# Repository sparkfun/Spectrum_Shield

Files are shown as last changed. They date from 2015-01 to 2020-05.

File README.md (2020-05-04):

SparkFun Spectrum Shield
========================

SparkFun Spectrum Shield (https://www.sparkfun.com/products/13116)

[*SparkFun Spectrum Shield (DEV-13116)*](https://www.sparkfun.com/products/13116)

 This shield can be used to create sound visualizers, detect patterns in music or add sound activation to your microcontroller projects.

Repository Contents
-------------------
* **/Firmware** - Example Arduino Sketch
* **/Hardware** - All Eagle design files (.brd, .sch)
* **/Production** - Test bed files and production panel files

Documentation
--------------
* **[Hookup Guide](https://learn.sparkfun.com/tutorials/spectrum-shield-hookup-guide-v2)** - Basic hookup guide for the Spectrum Shield.
* **[SparkFun Fritzing repo](https://github.com/sparkfun/Fritzing_Parts)** - Fritzing diagrams for SparkFun products.
* **[SparkFun 3D Model repo](https://github.com/sparkfun/3D_Models)** - 3D models of SparkFun products. 

Product Versions
----------------
* [DEV-13116](https://www.sparkfun.com/products/13116) - Version 1.6
* [DEV-10306](https://www.sparkfun.com/products/10306) - Version 1.4. Retired. 

License Information
-------------------

This product is _**open source**_! 

Please review the LICENSE.md file for license information. 

If you have any questions or concerns on licensing, please contact technical support on our [SparkFun forums](https://forum.sparkfun.com/viewforum.php?f=152).

Distributed as-is; no warranty is given.

- Your friends at SparkFun.

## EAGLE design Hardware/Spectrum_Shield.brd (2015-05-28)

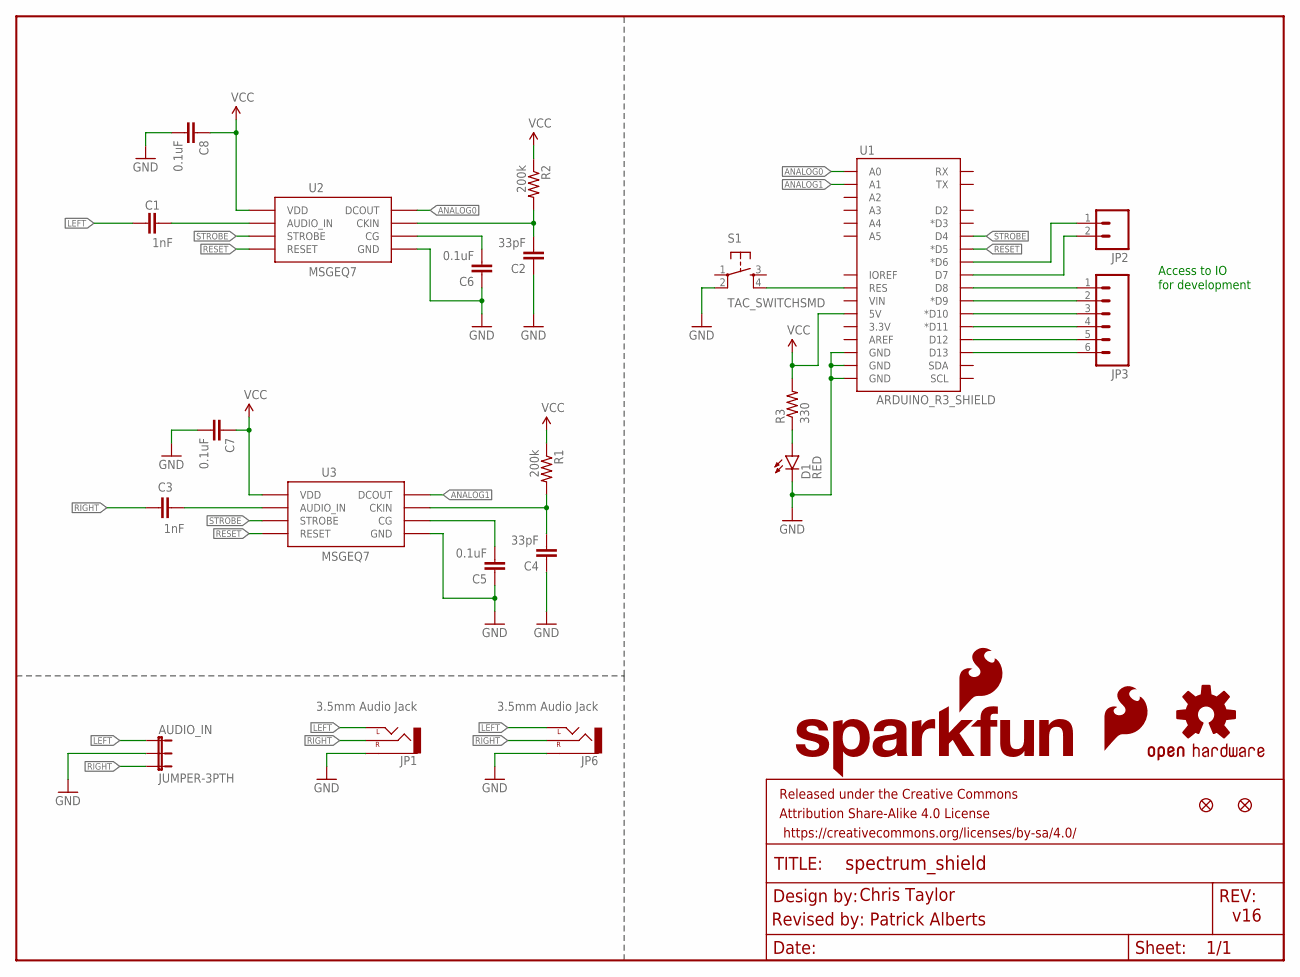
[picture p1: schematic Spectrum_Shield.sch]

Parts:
AUDIO_IN: JUMPER-3PTH; 1X03
C1, C3: 1nF; 0603-CAP
C2, C4: 33pF; 0603-CAP
C5, C6, C7, C8: 0.1uF; 0603-CAP
D1: RED; LED-0603
FRAME1: FRAME-LETTER; CREATIVE_COMMONS
JP1, JP6: 3.5mm Audio Jack; AUDIO-JACK-3.5MM-SMD
JP2: M02PTH; 1X02
JP3: M06SIP; 1X06
JP4, JP5: FIDUCIAL1X2; FIDUCIAL-1X2
LOGO1: OSHW-LOGOM; OSHW-LOGO-M
LOGO2: SFE_LOGO_FLAME.2_INCH; SFE_LOGO_FLAME_.2
LOGO3: SFE_LOGO_NAME_FLAME.1_INCH; SFE_LOGO_NAME_FLAME_.1
R1, R2: 200k; 0603-RES
R3: 330; 0603-RES
S1: TAC_SWITCHSMD; TACTILE-SWITCH-SMD
U1: ARDUINO_R3_SHIELD; UNO_R3_SHIELD
U2, U3: MSGEQ7SOIC; SOIC8

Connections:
ANALOG0: U1.A0, U2.3 (DCOUT)
ANALOG1: U1.A1, U3.3 (DCOUT)
GND: AUDIO_IN.2, C2.1, C4.1, C5.1, C6.1, C7.2, C8.2, D1.C, JP1.SLEEVE, JP6.SLEEVE, S1.2, U1.GND@0 (GND), U1.GND@1 (GND), U1.GND@2 (GND), U2.2 (GND), U3.2 (GND)
LEFT: AUDIO_IN.1, C1.1, JP1.TIP (LEFT), JP6.TIP (LEFT)
unnamed: C1.2, U2.5 (AUDIO_IN)
unnamed: C3.2, U3.5 (AUDIO_IN)
unnamed: C4.2, R1.2, U3.8 (CKIN)
unnamed: C2.2, R2.2, U2.8 (CKIN)
unnamed: C5.2, U3.6 (CG)
unnamed: C6.2, U2.6 (CG)
unnamed: D1.A, R3.1
unnamed: JP2.1, U1.D6 (*D6)
unnamed: JP2.2, U1.D7
unnamed: JP3.1, U1.D8
unnamed: JP3.2, U1.D9 (*D9)
unnamed: JP3.3, U1.D10 (*D10)
unnamed: JP3.4, U1.D11 (*D11)
unnamed: JP3.5, U1.D12
unnamed: JP3.6, U1.D13
unnamed: S1.4, U1.RES
RESET: U1.D5 (*D5), U2.7 (RESET), U3.7 (RESET)
RIGHT: AUDIO_IN.3, C3.1, JP1.RING (RIGHT), JP6.RING (RIGHT)
STROBE: U1.D4, U2.4 (STROBE), U3.4 (STROBE)
VCC: C7.1, C8.1, R1.1, R2.1, R3.2, U1.5V, U2.1 (VDD), U3.1 (VDD)

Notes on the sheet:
Access to IO
for development
v16
Chris Taylor
Revised by: Patrick Alberts

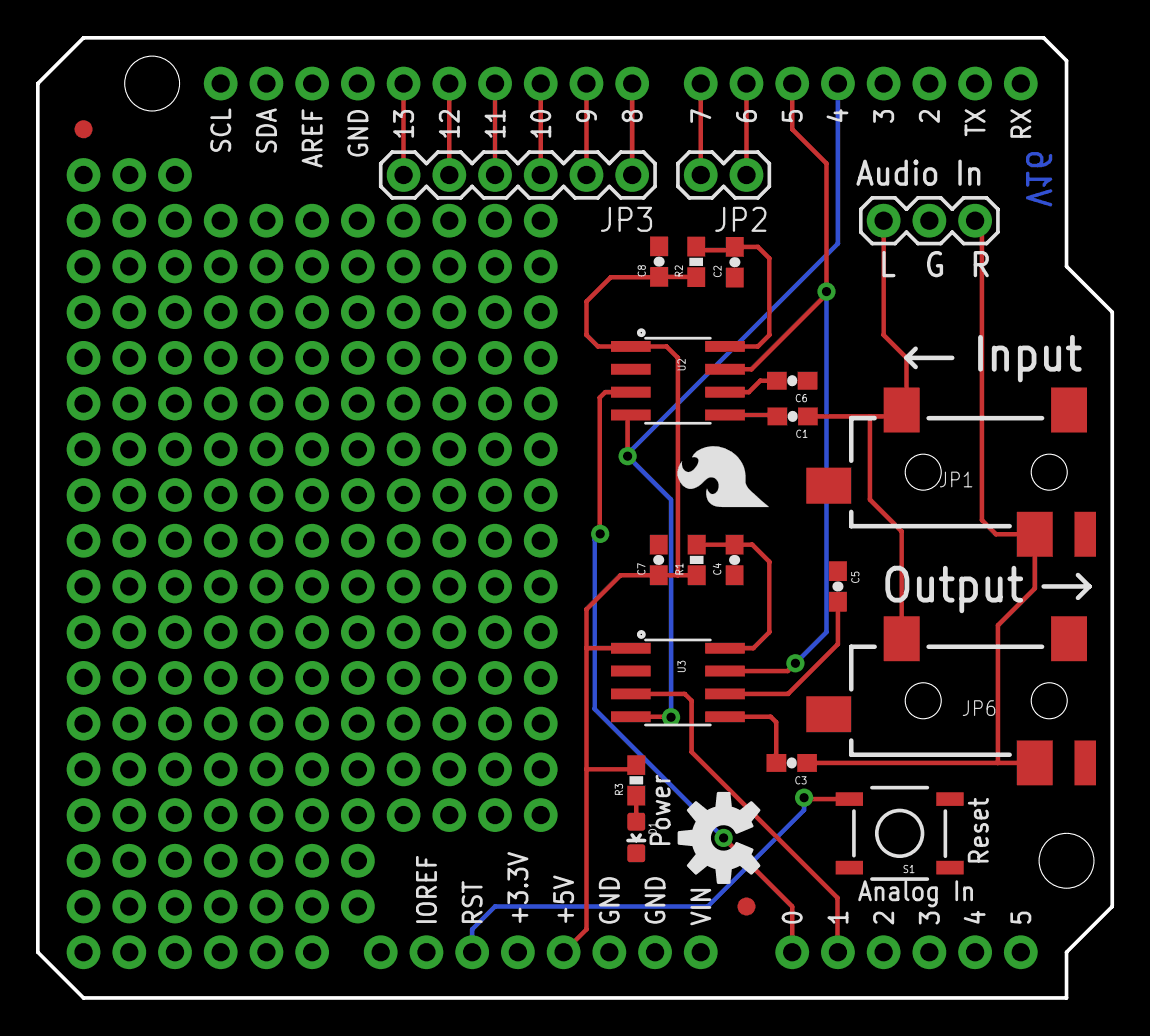
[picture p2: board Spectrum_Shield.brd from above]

Board: 2 copper layers, 59.7 x 53.3 mm, 29 parts (1 on the bottom side), 24 nets.

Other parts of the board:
U$1, U$3: STAND-OFF-TIGHT

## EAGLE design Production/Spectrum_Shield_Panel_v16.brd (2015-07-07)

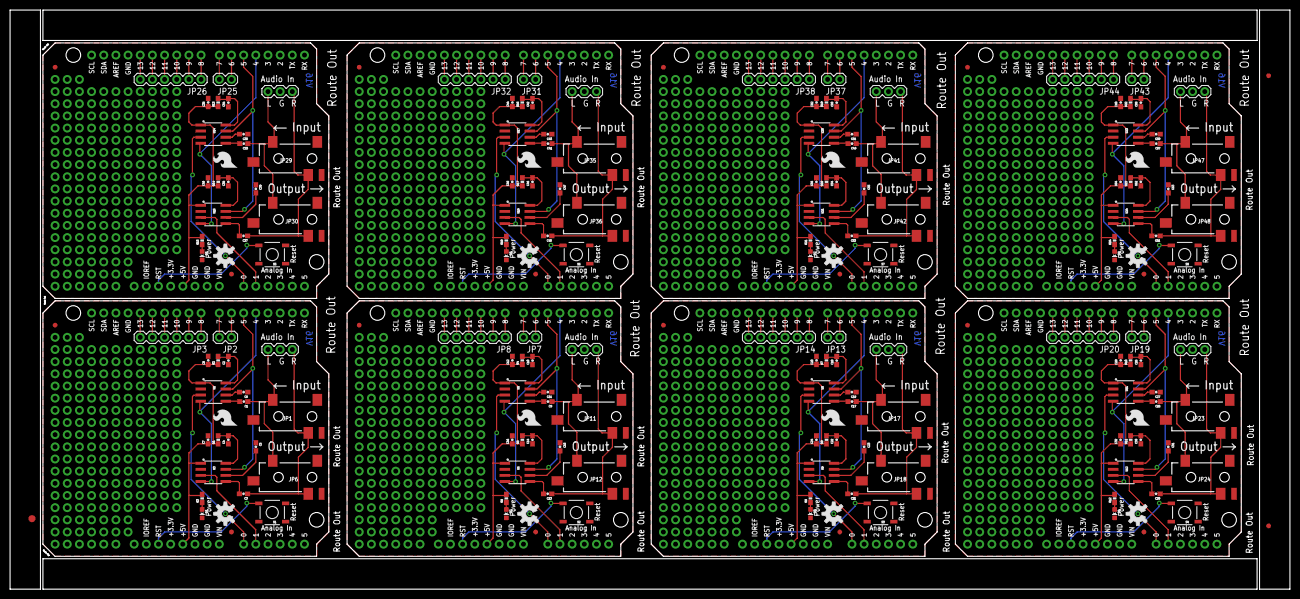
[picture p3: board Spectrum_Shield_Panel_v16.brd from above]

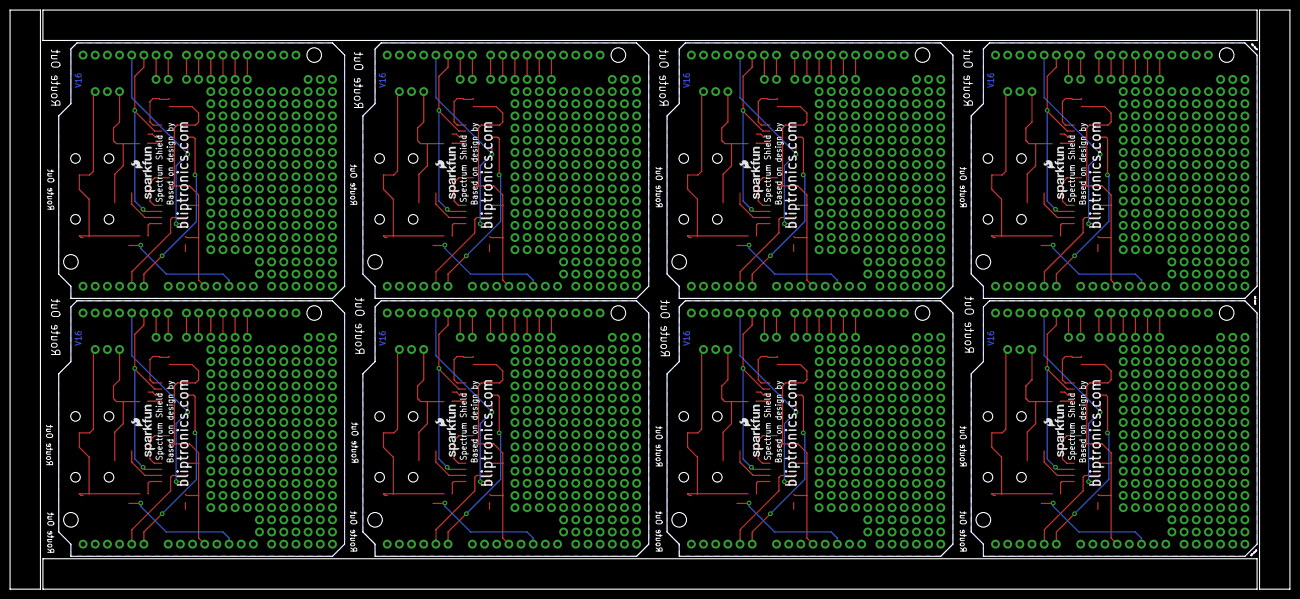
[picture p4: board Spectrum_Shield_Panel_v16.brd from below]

Board: 2 copper layers, 267.2 x 120.9 mm, 227 parts (8 on the bottom side), 192 nets.

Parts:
AUDIO_IN, AUDIO_IN1, AUDIO_IN2, AUDIO_IN3, AUDIO_IN4, AUDIO_IN5, AUDIO_IN6, AUDIO_IN7: JUMPER-3PTH; 1X03
C1, C3, C9, C13, C17, C21, C25, C29, C33, C37, C41, C45, C49, C53, C57, C61: 1nF; 0603-CAP
C2, C4, C10, C14, C18, C22, C26, C30, C34, C38, C42, C46, C50, C54, C58, C62: 33pF; 0603-CAP
C5, C6, C7, C8, C11, C12, C15, C16, C19, C20, C23, C24, C27, C28, C31, C32, C35, C36, C39, C40, C43, C44, C47, C48, C51, C52, C55, C56, C59, C60, C63, C64: 0.1uF; 0603-CAP
D1, D2, D3, D4, D5, D6, D7, D8: RED; LED-0603
E$1, E$2: FIDUCIAL-1X2
E$3: FIDUCIAL-1.5X3
JP1, JP6, JP11, JP12, JP17, JP18, JP23, JP24, JP29, JP30, JP35, JP36, JP41, JP42, JP47, JP48: 3.5mm Audio Jack; AUDIO-JACK-3.5MM-SMD
JP2, JP7, JP13, JP19, JP25, JP31, JP37, JP43: 1X02
JP3, JP8, JP14, JP20, JP26, JP32, JP38, JP44: 1X06
JP4, JP5, JP9, JP10, JP15, JP16, JP21, JP22, JP27, JP28, JP33, JP34, JP39, JP40, JP45, JP46: FIDUCIAL1X2; FIDUCIAL-1X2
LOGO1, LOGO4, LOGO7, LOGO10, LOGO13, LOGO16, LOGO19, LOGO22: OSHW-LOGOM; OSHW-LOGO-M
LOGO2, LOGO6, LOGO9, LOGO12, LOGO15, LOGO18, LOGO21, LOGO24: SFE_LOGO_FLAME.2_INCH; SFE_LOGO_FLAME_.2
LOGO3, LOGO5, LOGO8, LOGO11, LOGO14, LOGO17, LOGO20, LOGO23: SFE_LOGO_NAME_FLAME.1_INCH; SFE_LOGO_NAME_FLAME_.1
R1, R2, R4, R5, R7, R8, R10, R11, R13, R14, R16, R17, R19, R20, R22, R23: 200k; 0603-RES
R3, R6, R9, R12, R15, R18, R21, R24: 330; 0603-RES
S1, S2, S3, S4, S5, S6, S7, S8: TAC_SWITCHSMD; TACTILE-SWITCH-SMD
U1, U4, U7, U10, U13, U16, U19, U22: ARDUINO_R3_SHIELD; UNO_R3_SHIELD
U2, U3, U5, U6, U8, U9, U11, U12, U14, U15, U17, U18, U20, U21, U23, U24: MSGEQ7SOIC; SOIC8
U$1, U$2, U$3, U$4, U$5, U$6, U$7, U$8, U$9, U$10, U$11, U$12, U$13, U$14, U$15, U$16: STAND-OFF-TIGHT

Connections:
ANALOG0: U1.A0, U2.3
ANALOG1: U1.A1, U3.3
ANALOG2: U4.A0, U5.3
ANALOG3: U4.A1, U6.3
ANALOG4: U7.A0, U8.3
ANALOG5: U7.A1, U9.3
ANALOG6: U10.A0, U11.3
ANALOG7: U10.A1, U12.3
ANALOG8: U13.A0, U14.3
ANALOG9: U13.A1, U15.3
ANALOG10: U16.A0, U17.3
ANALOG11: U16.A1, U18.3
ANALOG12: U19.A0, U20.3
ANALOG13: U19.A1, U21.3
ANALOG14: U22.A0, U23.3
ANALOG15: U22.A1, U24.3
GND: AUDIO_IN.2, C2.1, C4.1, C5.1, C6.1, C7.2, C8.2, D1.C, JP1.SLEEVE, JP6.SLEEVE, S1.2, U1.GND@0, U1.GND@1, U1.GND@2, U2.2, U3.2
GND1: AUDIO_IN1.2, C10.1, C11.1, C12.2, C14.1, C15.1, C16.2, D2.C, JP11.SLEEVE, JP12.SLEEVE, S2.2, U4.GND@0, U4.GND@1, U4.GND@2, U5.2, U6.2
GND2: AUDIO_IN2.2, C18.1, C19.1, C20.2, C22.1, C23.1, C24.2, D3.C, JP17.SLEEVE, JP18.SLEEVE, S3.2, U7.GND@0, U7.GND@1, U7.GND@2, U8.2, U9.2
GND3: AUDIO_IN3.2, C26.1, C27.1, C28.2, C30.1, C31.1, C32.2, D4.C, JP23.SLEEVE, JP24.SLEEVE, S4.2, U10.GND@0, U10.GND@1, U10.GND@2, U11.2, U12.2
GND4: AUDIO_IN4.2, C34.1, C35.1, C36.2, C38.1, C39.1, C40.2, D5.C, JP29.SLEEVE, JP30.SLEEVE, S5.2, U13.GND@0, U13.GND@1, U13.GND@2, U14.2, U15.2
GND5: AUDIO_IN5.2, C42.1, C43.1, C44.2, C46.1, C47.1, C48.2, D6.C, JP35.SLEEVE, JP36.SLEEVE, S6.2, U16.GND@0, U16.GND@1, U16.GND@2, U17.2, U18.2
GND6: AUDIO_IN6.2, C50.1, C51.1, C52.2, C54.1, C55.1, C56.2, D7.C, JP41.SLEEVE, JP42.SLEEVE, S7.2, U19.GND@0, U19.GND@1, U19.GND@2, U20.2, U21.2
GND7: AUDIO_IN7.2, C58.1, C59.1, C60.2, C62.1, C63.1, C64.2, D8.C, JP47.SLEEVE, JP48.SLEEVE, S8.2, U22.GND@0, U22.GND@1, U22.GND@2, U23.2, U24.2
LEFT: AUDIO_IN.1, C1.1, JP1.TIP, JP6.TIP
LEFT1: AUDIO_IN1.1, C9.1, JP11.TIP, JP12.TIP
LEFT2: AUDIO_IN2.1, C17.1, JP17.TIP, JP18.TIP
LEFT3: AUDIO_IN3.1, C25.1, JP23.TIP, JP24.TIP
LEFT4: AUDIO_IN4.1, C33.1, JP29.TIP, JP30.TIP
LEFT5: AUDIO_IN5.1, C41.1, JP35.TIP, JP36.TIP
LEFT6: AUDIO_IN6.1, C49.1, JP41.TIP, JP42.TIP
LEFT7: AUDIO_IN7.1, C57.1, JP47.TIP, JP48.TIP
unnamed: C1.2, U2.5
unnamed: C3.2, U3.5
unnamed: C4.2, R1.2, U3.8
unnamed: C2.2, R2.2, U2.8
unnamed: C5.2, U3.6
unnamed: C6.2, U2.6
unnamed: D1.A, R3.1
unnamed: JP2.1, U1.D6
unnamed: JP2.2, U1.D7
unnamed: JP3.1, U1.D8
unnamed: JP3.2, U1.D9
unnamed: JP3.3, U1.D10
unnamed: JP3.4, U1.D11
unnamed: JP3.5, U1.D12
unnamed: JP3.6, U1.D13
unnamed: C9.2, U5.5
unnamed: C10.2, R4.2, U5.8
unnamed: C11.2, U5.6
unnamed: C13.2, U6.5
unnamed: C14.2, R5.2, U6.8
unnamed: C15.2, U6.6
unnamed: D2.A, R6.1
unnamed: JP7.2, U4.D7
unnamed: JP8.1, U4.D8
unnamed: JP8.2, U4.D9
unnamed: JP8.3, U4.D10
unnamed: JP8.4, U4.D11
unnamed: JP8.5, U4.D12
unnamed: JP8.6, U4.D13
unnamed: S1.4, U1.RES
unnamed: S2.4, U4.RES
unnamed: JP7.1, U4.D6
unnamed: C17.2, U8.5
unnamed: C18.2, R7.2, U8.8
unnamed: C19.2, U8.6
unnamed: C21.2, U9.5
unnamed: C22.2, R8.2, U9.8
unnamed: C23.2, U9.6
unnamed: D3.A, R9.1
unnamed: JP13.2, U7.D7
unnamed: JP14.1, U7.D8
unnamed: JP14.2, U7.D9
unnamed: JP14.3, U7.D10
unnamed: JP14.4, U7.D11
unnamed: JP14.5, U7.D12
unnamed: JP14.6, U7.D13
unnamed: S3.4, U7.RES
unnamed: JP13.1, U7.D6
unnamed: C25.2, U11.5
unnamed: C26.2, R10.2, U11.8
unnamed: C27.2, U11.6
unnamed: C29.2, U12.5
unnamed: C30.2, R11.2, U12.8
unnamed: C31.2, U12.6
unnamed: D4.A, R12.1
unnamed: JP19.2, U10.D7
unnamed: JP20.1, U10.D8
unnamed: JP20.2, U10.D9
unnamed: JP20.3, U10.D10
unnamed: JP20.4, U10.D11
unnamed: JP20.5, U10.D12
unnamed: JP20.6, U10.D13
unnamed: S4.4, U10.RES
unnamed: JP19.1, U10.D6
unnamed: C33.2, U14.5
unnamed: C34.2, R13.2, U14.8
unnamed: C35.2, U14.6
unnamed: C37.2, U15.5
unnamed: C38.2, R14.2, U15.8
unnamed: C39.2, U15.6
unnamed: D5.A, R15.1
unnamed: JP25.2, U13.D7
unnamed: JP26.1, U13.D8
unnamed: JP26.2, U13.D9
unnamed: JP26.3, U13.D10
unnamed: JP26.4, U13.D11
unnamed: JP26.5, U13.D12
unnamed: JP26.6, U13.D13
unnamed: S5.4, U13.RES
unnamed: JP25.1, U13.D6
unnamed: C41.2, U17.5
unnamed: C42.2, R16.2, U17.8
unnamed: C43.2, U17.6
unnamed: C45.2, U18.5
unnamed: C46.2, R17.2, U18.8
unnamed: C47.2, U18.6
unnamed: D6.A, R18.1
unnamed: JP31.2, U16.D7
unnamed: JP32.1, U16.D8
unnamed: JP32.2, U16.D9
unnamed: JP32.3, U16.D10
unnamed: JP32.4, U16.D11
unnamed: JP32.5, U16.D12
unnamed: JP32.6, U16.D13
unnamed: S6.4, U16.RES
unnamed: JP31.1, U16.D6
unnamed: C49.2, U20.5
unnamed: C50.2, R19.2, U20.8
unnamed: C51.2, U20.6
unnamed: C53.2, U21.5
unnamed: C54.2, R20.2, U21.8
unnamed: C55.2, U21.6
unnamed: D7.A, R21.1
unnamed: JP37.2, U19.D7
unnamed: JP38.1, U19.D8
unnamed: JP38.2, U19.D9
unnamed: JP38.3, U19.D10
unnamed: JP38.4, U19.D11
unnamed: JP38.5, U19.D12
unnamed: JP38.6, U19.D13
unnamed: S7.4, U19.RES
unnamed: JP37.1, U19.D6
unnamed: C57.2, U23.5
unnamed: C58.2, R22.2, U23.8
unnamed: C59.2, U23.6
unnamed: C61.2, U24.5
unnamed: C62.2, R23.2, U24.8
unnamed: C63.2, U24.6
unnamed: D8.A, R24.1
unnamed: JP43.2, U22.D7
unnamed: JP44.1, U22.D8
unnamed: JP44.2, U22.D9
unnamed: JP44.3, U22.D10
unnamed: JP44.4, U22.D11
unnamed: JP44.5, U22.D12
unnamed: JP44.6, U22.D13
unnamed: S8.4, U22.RES
unnamed: JP43.1, U22.D6
RESET: U1.D5, U2.7, U3.7
RESET1: U4.D5, U5.7, U6.7
RESET2: U7.D5, U8.7, U9.7
RESET3: U10.D5, U11.7, U12.7
RESET4: U13.D5, U14.7, U15.7
RESET5: U16.D5, U17.7, U18.7
RESET6: U19.D5, U20.7, U21.7
RESET7: U22.D5, U23.7, U24.7
RIGHT: AUDIO_IN.3, C3.1, JP1.RING, JP6.RING
RIGHT1: AUDIO_IN1.3, C13.1, JP11.RING, JP12.RING
RIGHT2: AUDIO_IN2.3, C21.1, JP17.RING, JP18.RING
RIGHT3: AUDIO_IN3.3, C29.1, JP23.RING, JP24.RING
RIGHT4: AUDIO_IN4.3, C37.1, JP29.RING, JP30.RING
RIGHT5: AUDIO_IN5.3, C45.1, JP35.RING, JP36.RING
RIGHT6: AUDIO_IN6.3, C53.1, JP41.RING, JP42.RING
RIGHT7: AUDIO_IN7.3, C61.1, JP47.RING, JP48.RING
STROBE: U1.D4, U2.4, U3.4
STROBE1: U4.D4, U5.4, U6.4
STROBE2: U7.D4, U8.4, U9.4
STROBE3: U10.D4, U11.4, U12.4
STROBE4: U13.D4, U14.4, U15.4
STROBE5: U16.D4, U17.4, U18.4
STROBE6: U19.D4, U20.4, U21.4
STROBE7: U22.D4, U23.4, U24.4
VCC: C7.1, C8.1, R1.1, R2.1, R3.2, U1.5V, U2.1, U3.1
VCC1: C12.1, C16.1, R4.1, R5.1, R6.2, U4.5V, U5.1, U6.1
VCC2: C20.1, C24.1, R7.1, R8.1, R9.2, U7.5V, U8.1, U9.1
VCC3: C28.1, C32.1, R10.1, R11.1, R12.2, U10.5V, U11.1, U12.1
VCC4: C36.1, C40.1, R13.1, R14.1, R15.2, U13.5V, U14.1, U15.1
VCC5: C44.1, C48.1, R16.1, R17.1, R18.2, U16.5V, U17.1, U18.1
VCC6: C52.1, C56.1, R19.1, R20.1, R21.2, U19.5V, U20.1, U21.1
VCC7: C60.1, C64.1, R22.1, R23.1, R24.2, U22.5V, U23.1, U24.1

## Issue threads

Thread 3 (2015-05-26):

Issues from v16 proto Checklist

ericorosel, 2015-05-26:
(1) Currently there are two 4-way junctions: both below each MSGEQ7 symbol, each 4-way needs to split up into two 3-way junctions.

(2) On the R3 symbol the VCC net crosses over the RESET net. It would be nice to reorganize these nets to eliminate the intersection all together.

(3) The Audio jacks are currently named Audiojack1 and 2, these should have a name that uses the proper connector prefix (JPx) x being a number

(4) Two vias have tStop and bStop polygons set over them: the first is right next to the OSHW silk, and the other is below U2 (the upper MSGEQ7 IC). These are not used for testing

(5) Audio jacks need a name and value in BRD

(6) Need measures that include the standoffs

(7) As of now the name of the product is not on the board; the previous rev was without a silk for the product name as well (figured I would bring it up). Also, it would be nice to get an SFE flame on the top of the board, like the previous rev.

that's it

ericorosel, 2015-05-28:
All fixed

Closed 2015-05-28.

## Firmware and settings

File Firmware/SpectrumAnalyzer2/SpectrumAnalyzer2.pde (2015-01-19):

#include <LEDPixels.h>

//Example to control RGB LED Modules with Spectrum Analyzer
//Bliptronics.com
//Ben Moyes 2010
//Use this as you wish, but please give credit, or at least buy some of my LEDs!
//


LEDPixels LP;  //Our LEDPixels library - see http://www.bliptronics.com/ArduinoCode/LEDPixels.zip
   
//For spectrum analyzer shield, these three pins are used.
//You can move pinds 4 and 5, but you must cut the trace on the shield and re-route from the 2 jumpers. 
int spectrumReset=5;
int spectrumStrobe=4;
int spectrumAnalog=0;  //0 for left channel, 1 for right.

//This holds the 15 bit RGB values for each LED.
//You'll need one for each LED, we're using 25 LEDs here.
//Note you've only got limited memory, so you can only control 
//Several hundred LEDs on a normal arduino. Double that on a Duemilanove.

int MyDisplay[25];

// Spectrum analyzer read values will be kept here.
int Spectrum[7];

void setup() {
  byte Counter;

  //Initialize the LEDPixels library.
  //            refresh delay, address of data, number of LEDs, clock pin, data pin.
  LP.initialize(25, &MyDisplay[0],25, 12, 11 );

  //Setup pins to drive the spectrum analyzer. 
  pinMode(spectrumReset, OUTPUT);
  pinMode(spectrumStrobe, OUTPUT);

  //Init spectrum analyzer
  digitalWrite(spectrumStrobe,LOW);
    delay(1);
  digitalWrite(spectrumReset,HIGH);
    delay(1);
  digitalWrite(spectrumStrobe,HIGH);
    delay(1);
  digitalWrite(spectrumStrobe,LOW);
    delay(1);
  digitalWrite(spectrumReset,LOW);
    delay(5);
  // Reading the analyzer now will read the lowest frequency.
  
  // Turn all LEDs off.
  LP.setRange(0,24,LP.color(0,0,0));
  LP.show();                             //Write out display to LEDs

}

void loop() {

  int Counter, Counter2, Counter3;
    
  showSpectrum();
  delay(15);  //We wait here for a little while until all the values to the LEDs are written out.
              //This is being done in the background by an interrupt.
}

// Read 7 band equalizer.
void readSpectrum()
{
  // Band 0 = Lowest Frequencies.
  byte Band;
  for(Band=0;Band <7; Band++)
  {
    Spectrum[Band] = (analogRead(spectrumAnalog) + analogRead(spectrumAnalog) ) >>1; //Read twice and take the average by dividing by 2
    digitalWrite(spectrumStrobe,HIGH);
    digitalWrite(spectrumStrobe,LOW);     
  }
}


void showSpectrum()
{
  //Not I don;t use any floating point numbers - all integers to keep it zippy. 
   readSpectrum();
   byte Band, BarSize, MaxLevel;
   static unsigned int  Divisor = 80, ChangeTimer=0; //, ReminderDivisor,
   unsigned int works, Remainder;
  
  MaxLevel = 0; 
        
  for(Band=0;Band<5;Band++)//We only graph the lowest 5 bands here, there is 2 more unused!
  {
  //If value is 0, we don;t show anything on graph
     works = Spectrum[Band]/Divisor;	//Bands are read in as 10 bit values. Scale them down to be 0 - 5
     if(works > MaxLevel)  //Check if this value is the largest so far.
       MaxLevel = works;                       
     for(BarSize=1;BarSize <=5; BarSize++)  
        {
        if(	works > BarSize) LP.setLEDFast(	LP.Translate(Band,BarSize-1),BarSize*6,31-(BarSize*5),0);
          else if ( works == BarSize) LP.setLEDFast(	LP.Translate(Band,BarSize-1),BarSize*6,31-(BarSize*5),0); //Was remainder
            else LP.setLEDFast(	LP.Translate(Band,BarSize-1),5,0,5);
        }
  }
  LP.show();

 // Adjust the Divisor if levels are too high/low.
 // If  below 4 happens 20 times, then very slowly turn up.
  if (MaxLevel >= 5)
  {
    Divisor=Divisor+1;
    ChangeTimer=0;
  }
  else
    if(MaxLevel < 4)
    {
      if(Divisor > 65)
        if(ChangeTimer++ > 20)
        {
          Divisor--;
          ChangeTimer=0;
        }
    }
    else
    {
      ChangeTimer=0; 
    }
  }




 
    

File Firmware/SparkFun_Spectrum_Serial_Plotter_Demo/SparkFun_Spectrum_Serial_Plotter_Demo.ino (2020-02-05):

/******************************************************************************
  SparkFun Spectrum Shield Demo
  Wes Furuya @ SparkFun Electronics
  January 2020
  https://github.com/sparkfun/Spectrum_Shield

  This sketch shows the basic functionality of the Spectrum Shield, using the Serial Monitor/Plotter.

  The Spectrum Shield code is based off of the original demo sketch by Toni Klopfenstein @SparkFun Electronics.
  This sketch is available in the Spectrum Shield repository.

  Development environment specifics:
  Developed in Arduino 1.8.5
*********************************************************************************/

//Declare Spectrum Shield pin connections
#define STROBE 4
#define RESET 5
#define DC_One A0
#define DC_Two A1

//Define spectrum variables
int freq_amp;
int Frequencies_One[7];
int Frequencies_Two[7];
int i;

/********************Setup Loop*************************/
void setup() {
  //Set spectrum Shield pin configurations
  pinMode(STROBE, OUTPUT);
  pinMode(RESET, OUTPUT);
  pinMode(DC_One, INPUT);
  pinMode(DC_Two, INPUT);

  //Initialize Spectrum Analyzers
  digitalWrite(STROBE, LOW);
  digitalWrite(RESET, LOW);
  delay(5);

  Serial.begin(9600);
}


/**************************Main Function Loop*****************************/
void loop() {
  Read_Frequencies();
  Graph_Frequencies();

}


/*******************Pull frquencies from Spectrum Shield********************/
void Read_Frequencies() {
  digitalWrite(RESET, HIGH);
  delayMicroseconds(200);
  digitalWrite(RESET, LOW);
  delayMicroseconds(200);

  //Read frequencies for each band
  for (freq_amp = 0; freq_amp < 7; freq_amp++)
  {
    digitalWrite(STROBE, HIGH);
    delayMicroseconds(50);
    digitalWrite(STROBE, LOW);
    delayMicroseconds(50);

    Frequencies_One[freq_amp] = analogRead(DC_One);
    Frequencies_Two[freq_amp] = analogRead(DC_Two);
  }
}

/*****************Print Out Band Values for Serial Plotter*****************/
void Graph_Frequencies() {
  for (i = 0; i < 7; i++)
  {
//    Serial.print(Frequencies_One[i]);
//    Serial.print(" ");
//    Serial.print(Frequencies_Two[i]);
//    Serial.print(" ");
    Serial.print( (Frequencies_One[i] + Frequencies_Two[i]) / 2 );
    Serial.print("    ");
  }
  Serial.println();
}

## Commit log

2014-07-16 int commit
    [Spectrum_Shield.brd, Spectrum_Shield.sch]
2014-07-18 Computer Change
    [Spectrum_Shield.brd, Spectrum_Shield.sch]
2014-07-21 computer change #2
    [Spectrum_Shield.brd, Spectrum_Shield.sch]
2014-07-22 Upd audiojk/0603/ trace re-routes
    Updated the audio jack to smd, changed res/caps to 0603 as well as the
    LED. Added the OSHW logo and updated the shield to the R3.
    [Spectrum_Shield.brd, Spectrum_Shield.sch]
2014-07-22 Trace Clean up.
    [Spectrum_Shield.brd]
2014-08-18 Fixed Sch, Added Input/Output Silk
    [Spectrum_Shield.brd, Spectrum_Shield.sch]
2014-09-30 changed silk
    [Spectrum_Shield.brd]
2014-10-10 moved fiducials
    [Spectrum_Shield.brd]
2014-10-10 created panel v15
    [Spectrum_Shield-Panel-v15.brd]
2014-11-11 Fixing a few flags on schematic
2015-02-24 Adding in demo sketches, fixing Production directory name
    [Spectrum_Shield-Panel-v15.brd, Spectrum_Shield.sch]
2015-05-12 Fixed Ground Issue
    [Spectrum_Shield.brd, Spectrum_Shield.sch]
2015-05-12 QC checklist updated, fixed gnd / pin issue
    [Spectrum_Shield.brd, Spectrum_Shield.sch]
2015-05-12 Fixed acid traps
    [Spectrum_Shield.brd, Spectrum_Shield.sch]
2015-05-13 Fixed silk.
    [Spectrum_Shield.brd, Spectrum_Shield.sch]
2015-05-22 Added stand offs, fixed silk. QC list / attributes
    [Spectrum_Shield.brd, Spectrum_Shield.sch]
2015-05-28 Fixed QC Checklist Items
    1) Currently there are two 4-way junctions: both below each MSGEQ7
    symbol, each 4-way needs to split up into two 3-way junctions.
    (2) On the R3 symbol the VCC net crosses over the RESET net. It would be
    nice to reorganize these nets to eliminate the intersection all
    together.
    (3) The Audio jacks are currently named Audiojack1 and 2, these should
    have a name that uses the proper connector prefix (JPx) x being a number
    (4) Two vias have tStop and bStop polygons set over them: the first is
    right next to the OSHW silk, and the other is below U2 (the upper MSGEQ7
    IC). These are not used for testing
    (5) Audio jacks need a name and value in BRD
    (6) Need measures that i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
    [Spectrum_Shield.brd, Spectrum_Shield.sch]
2015-07-07 deleted old panel, created new v16 panel
    [Spectrum_Shield-Panel-v15.brd, Spectrum_Shield_Panel_v16.brd]
2015-12-14 Fixing pin declarations in code examples
    [SparkFun_PWM_Demo.ino, SparkFun_Spectrum_Demo.ino]

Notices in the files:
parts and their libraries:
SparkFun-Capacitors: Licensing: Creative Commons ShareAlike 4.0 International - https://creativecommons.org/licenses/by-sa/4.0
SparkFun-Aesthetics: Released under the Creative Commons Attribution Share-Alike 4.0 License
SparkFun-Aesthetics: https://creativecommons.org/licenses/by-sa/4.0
